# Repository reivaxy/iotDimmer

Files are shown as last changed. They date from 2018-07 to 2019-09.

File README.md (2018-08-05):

# iotDimmer

This Xiot agent is intended to control a dimmer for a lamp.

To use it, you'll preferrably also need the iotinator master module (https://github.com/reivaxy/iotinator), or you can just use it's REST API to integrate to your own designs.

You will find <a href="https://github.com/reivaxy/iotinator/wiki/07.-Dev-environnement-and-debug">here</a> all the information to install your dev environment.

I have a 15 year old big lamp that I like a lot (it was cheap !) which is equipped with a dimmer you are supposed to operate with your feet.

It's clumsy, it produces a little buzz at low level, and it's never easy to reach. Since this lamp is the main light source of my living room beside the sun, I'd like it to be a little more user friendly.

A zero crossing detection circuit sends rising edges on a pin used to trigger an interruption.

The interruption handler then computes a delay before sending a pulse to trigger a triac, to power the load (a lamp).

This way, the load is powered only between the pulse on the triac command and the next zero crossing. Changing the delay before the pulse on the triac for an incandescent bulb results in dimming the light it emits.

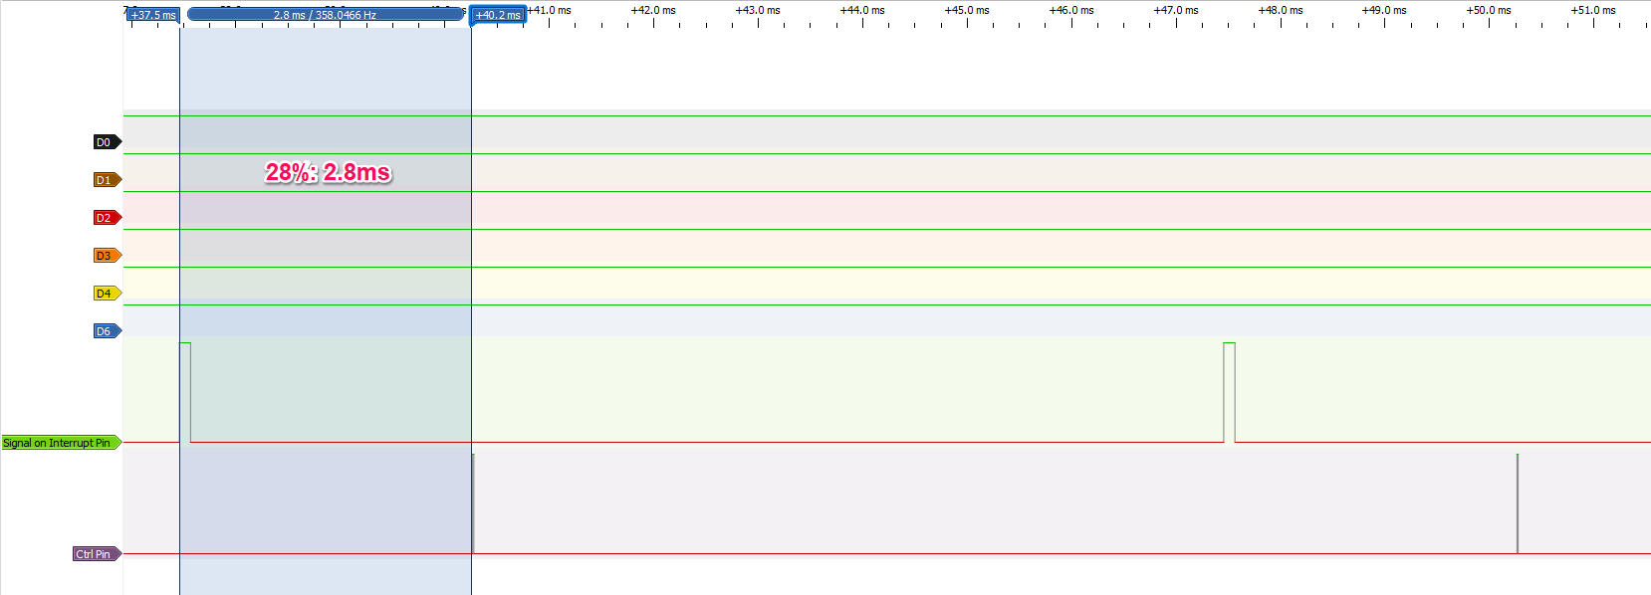
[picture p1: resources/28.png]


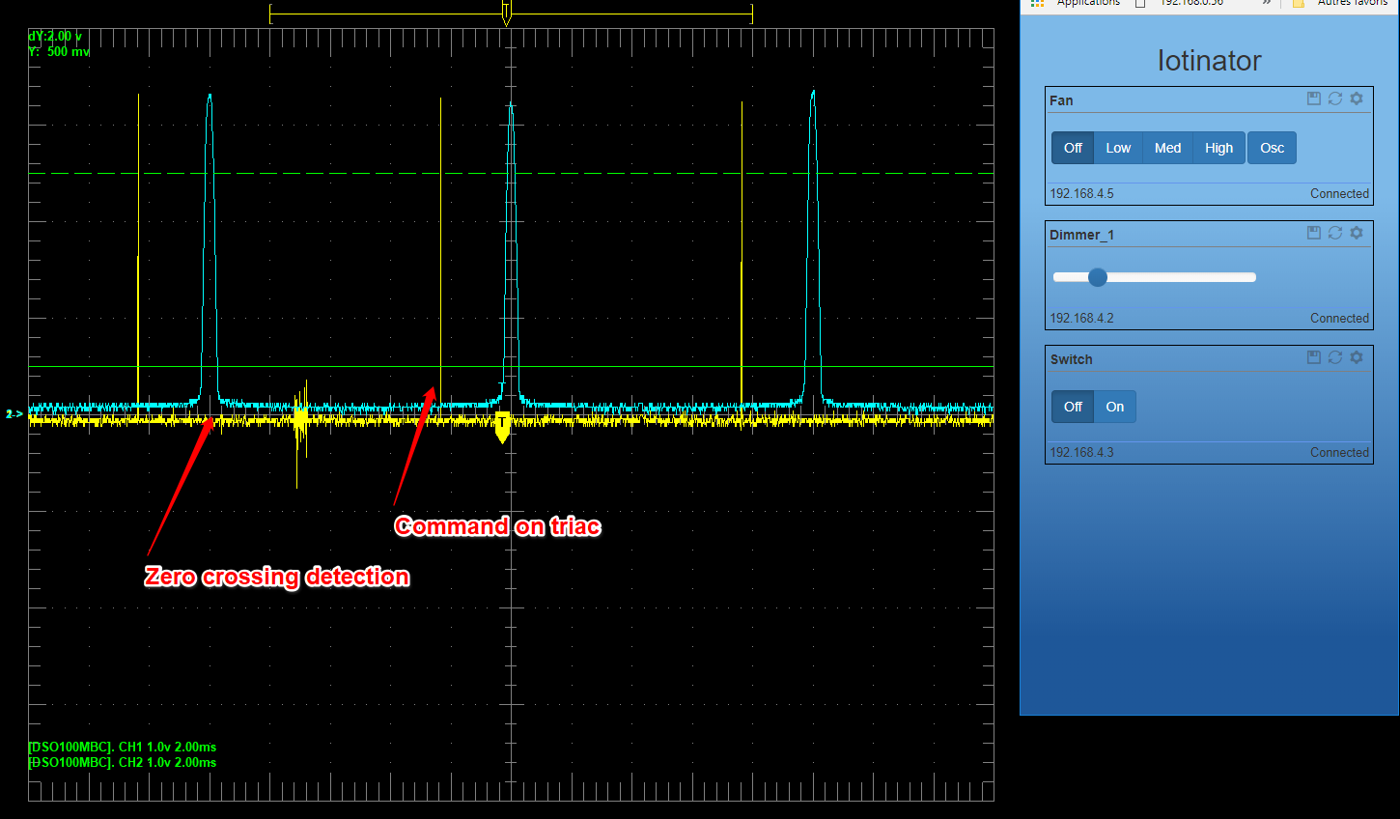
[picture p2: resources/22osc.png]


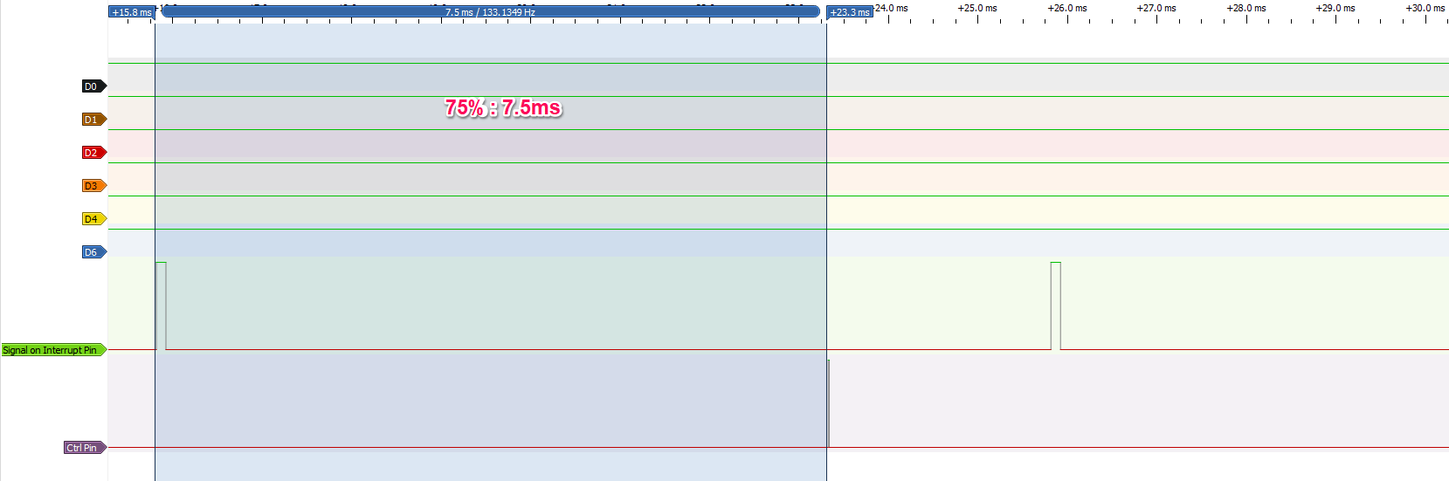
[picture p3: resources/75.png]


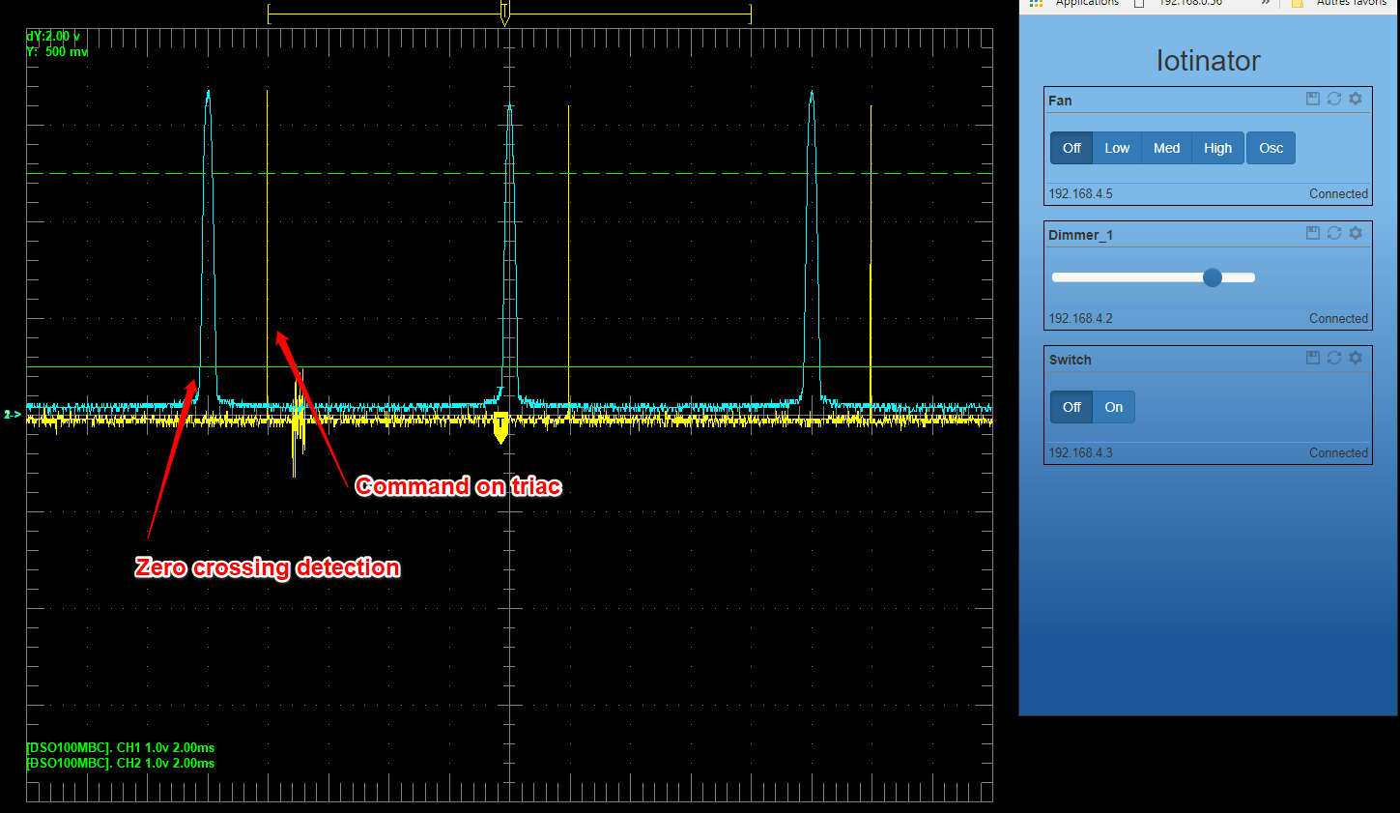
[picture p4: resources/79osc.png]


Here is the prototype for tests:

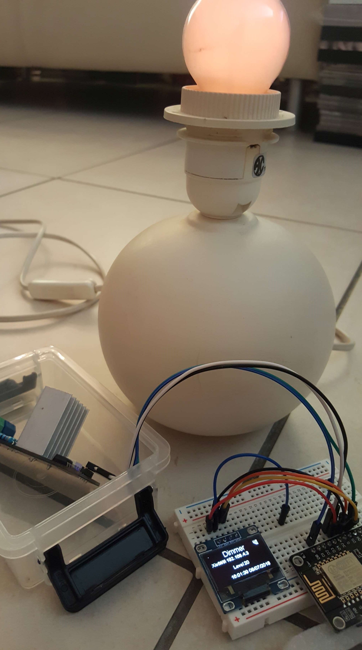
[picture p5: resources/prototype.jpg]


Here is the finished dimmer in its 3D printed case:

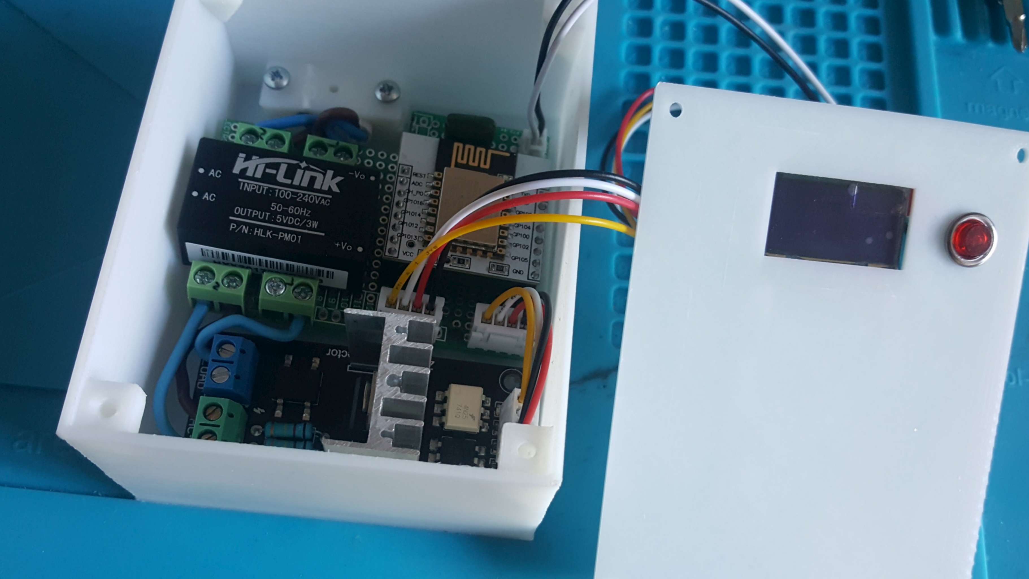
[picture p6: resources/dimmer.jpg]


And a screenshot of the webApp showing also two other modules:

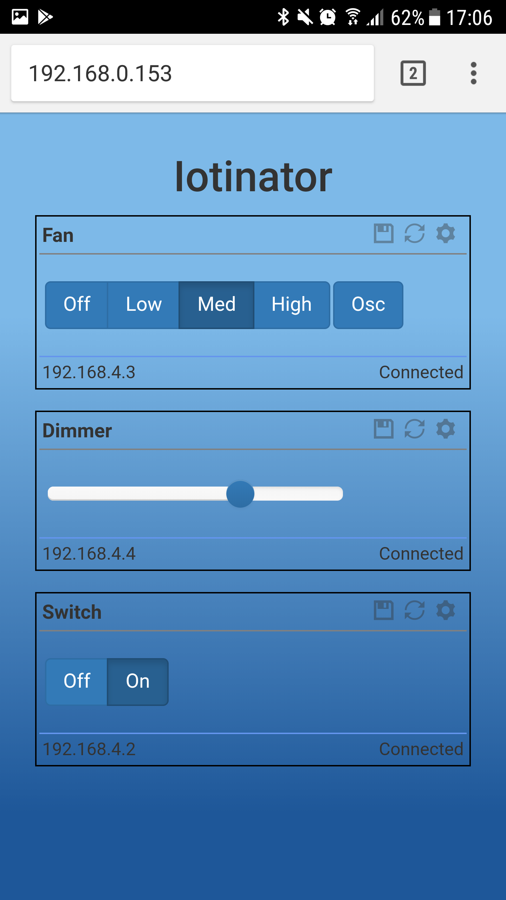
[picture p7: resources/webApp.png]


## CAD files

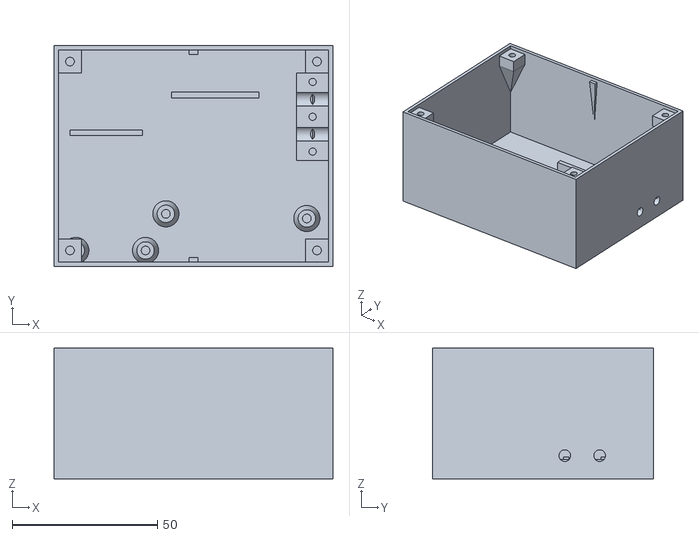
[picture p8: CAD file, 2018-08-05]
hardware/case.stl
96.0 x 76.0 x 45.0

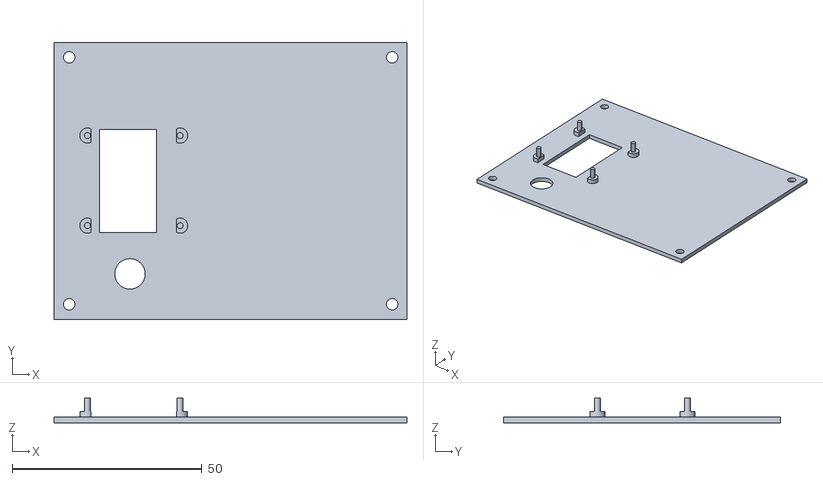
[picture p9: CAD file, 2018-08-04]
hardware/cover.stl
92.9 x 72.9 x 6.50

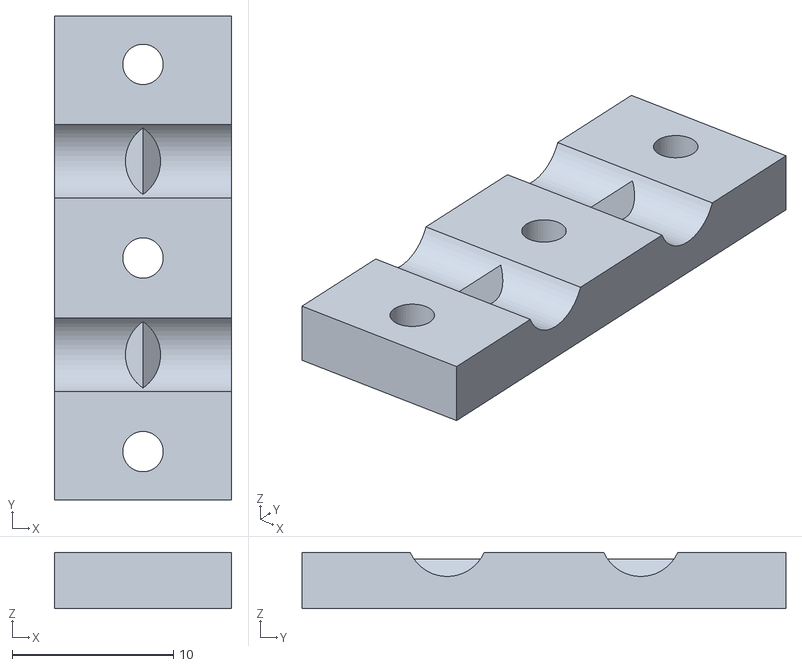
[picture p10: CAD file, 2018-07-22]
hardware/blocker.stl
11.0 x 30.0 x 3.50

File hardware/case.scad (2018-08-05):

include <../../iotinator/hardware/oledPanel.scad>;

// cover();
case();
// wireBlockerBottom();
// wireBlockerTop();
// test();
//reinforcement(wall, zi, 30);

wall = 1.5;

xi = 93;
yi = 73;
zi = 42;

x = xi + 2*wall;
y = yi + 2*wall;
z = zi + 2*wall;
bottomSpacerZ = 6;
xOffset = 6;

cornerSide = 8;
tolerance = 0.1;
oledPanelSide = 40;

module test() {
  translate([wall + tolerance/2, yi + wall + tolerance/2, z])
    rotate(180, [1, 0, 0])
      cover();
  case();
}

module cover()
{
  oledPosition = [1, (yi - tolerance - oledPanelSide) / 2, 0];
  difference()
  {
    union()
    {
      translate(oledPosition)
      rWindowPanel(oledPanelSide, oledPanelSide, wall, 0, 90);
      difference()
      {
        cube([xi - tolerance, yi - tolerance, wall]);
        translate([cornerSide / 2, cornerSide / 2, -1])
        cylinder(d = 3, h = wall + 2, $fn = 50);
        translate([cornerSide / 2, yi - cornerSide / 2, -1])
        cylinder(d = 3, h = wall + 2, $fn = 50);
        translate([xi - cornerSide / 2, cornerSide / 2, -1])
        cylinder(d = 3, h = wall + 2, $fn = 50);
        translate([xi - cornerSide / 2, yi - cornerSide / 2, -1])
        cylinder(d = 3, h = wall + 2, $fn = 50);
        // hole for the oled panel
        translate(oledPosition)
        {
          translate([0.5, 0.5, -0.5])
          cube([oledPanelSide - 1, oledPanelSide - 1, wall + 1]);
        }
      }
    }
    // Hole for the reset button
    translate([20, 12, -1])
    cylinder(d = 8, h = wall + 2, $fn = 50);
  }
}

module case() {
  difference() {
    cube([x, y, z]);  // outer shell
    translate([wall, wall, wall]) {
      cube([xi, yi, z]);
    }
    // Wire holes. TODO: params ! Should actually be part of wireBlockerBottom
    // But don't know how to make the difference for the holes...
    // or use same trick as with oled panel
    translate([xi, yi - 15.5, 8]) {
      rotate(90, [0, 1, 0]) {
        cylinder(d=4, h=5, $fn=50);
      }
    }
    translate([xi, yi - 27.5, 8]) {
      rotate(90, [0, 1, 0]) {
        cylinder(d=4, h=5, $fn=50);
      }
    }
  }
  // side reinforcement
  translate([x/2 + wall, wall, wall])
    rotate(90,[0, 0, 1])
      reinforcement(wall, zi, 20);

  // side reinforcement
  translate([x/2 - wall, y - wall, wall])
    rotate(-90,[0, 0, 1])
      reinforcement(wall, zi, 20);
  
  translate([x - 11 - wall, y - 30 - wall - 8, wall]) {
    wireBlockerBottom();
  }
  // screws for triac board
  translate([wall + xOffset, wall + 4, wall]) {
    bottomSpacer(3);
  }
  translate([wall + xOffset + 24, wall + 4, wall]) {
    bottomSpacer(3);
  }
  // Support for triac board
  translate([wall + 4, 45, wall]) {
    cube([25, 2, bottomSpacerZ]);
  }
  // Support for esp board
  translate([wall + 4 + 35, yi - 15, wall]) {
    cube([30, 2, bottomSpacerZ]);
  }

  // screws for esp board
  translate([wall + xOffset + 31, wall + 4 + 12.6, wall]) {
    bottomSpacer(3);
  }
  translate([wall + xOffset + 31 + 48.5, wall + 4 + 11, wall]) {
    bottomSpacer(3);
  }

  // corners to support the cover
  translate([wall, wall, wall])
    corner(cornerSide, zi, 20);
  translate([xi + wall, wall, wall])
    rotate(90, [0, 0, 1])
      corner(cornerSide, zi, 20);
  translate([xi + wall, yi + wall, wall])
    rotate(180, [0, 0, 1])
      corner(cornerSide, zi, 20);
  translate([wall, yi + wall, wall])
    rotate(-90, [0, 0, 1])
      corner(cornerSide, zi, 20);
}

module bottomSpacer(screwDiam) {
  translate([0, 0, 0]) {
    difference() {
      cylinder(d1 = screwDiam + 6, d2 = screwDiam + 3, h = bottomSpacerZ, $fn=50);
      translate([0, 0, 1]) {
        cylinder(d = screwDiam, h = bottomSpacerZ, $fn=50);
      }
    }
  }
}

module wireBlockerBottom(z = 6, screwThrew = false) {
  y = 30;
  x = 11;
  difference() {
    union() {
      difference() {
        cube([x, y, z]);
        // wire passage
        translate([-0.1, 9, z+1]) {
           rotate(90, [0, 1, 0]) {
             cylinder(d=5, h=x+2, $fn=50);
           }
        }
        translate([-0.1, y - 9, z+1]) {
           rotate(90, [0, 1, 0]) {
             cylinder(d=5, h=x+2, $fn=50);
           }
        }
      }
      // bottom edge to improve grip on wire
      color("lime") {
        side = z/2;
        translate([(x - sqrt(2 * side * side))/2, 0, z/2 + 0.1]) {
          rotate(45, [0, 1, 0]) {
            cube([side, y, side]);
          }
        }
      }
    }
    // Screw holes
    translate([x/2, 3, screwThrew?-0.1:0.1]) {
      cylinder(d=2.5, h=6, $fn=50);
    }
    translate([x/2, y - 3, screwThrew?-0.1:0.1]) {
      cylinder(d=2.5, h=6, $fn=50);
    }
     translate([x/2, y/2, screwThrew?-0.1:0.1]) {
       cylinder(d=2.5, h=6, $fn=50);
    }
  }
}

module wireBlockerTop() {
  wireBlockerBottom(z = 3.5, screwThrew = true);
}

module reinforcement(side, height, zOffset) {
  angle = 20;
  translate([0, side, 0])
    difference() {
      translate([0, 0, zOffset])
        linear_extrude(height = height - zOffset, center = false, convexity = 10, scale=side*200)
          square(size = .01, center = true);
      translate([-side, -side, 0])
        cube([side, side*2, height +1]);
    }
} 

module corner(side, height, zOffset, holeDiam = 3) {
  angle = 20;
  difference() {
    color("aqua") {
     translate([0, 0, height - 5]) {
       difference() {
         cube([side, side, 5]);
         translate([side/2, side/2, 0.1]) {
           cylinder(d=holeDiam, h=6, $fn=50);
         }
       }
     }
     translate([0, 0, zOffset])
      linear_extrude(height = height - zOffset - 5, center = false, convexity = 10, scale=side*200)
         square(size = .01, center = true);
    }
    translate([-side, -side, 0])
      cube([side, side, height]);
    translate([-side, 0, 0])
      cube([side, side, height]);
    translate([0, -side, 0])
      cube([side, side, height]);
  }
}

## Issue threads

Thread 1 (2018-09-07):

Add an arduino nano to handle the ZX and triac

reivaxy, 2018-09-07:
The first version of the dimmer used to start handling the zero-crossed exception as soon as the module was powered.
Now, to ensure a faster connection to the master wifi network, the interruption handler is set only once the agent is connected.
As a result, there is a delay before the dimmed device turns on.

A nano arduino could handle the ZC interruption and drive the triac. The ESP would just provide it (through serial) with the delay value when it's changed.

Problem: OTA! The code for the Nano would have to be flashed by the ESP through the serial port... This is a lot of work.

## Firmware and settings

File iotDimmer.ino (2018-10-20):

/**
 *  iotinator Dimmer Agent module
 *  Xavier Grosjean 2018
 *  Creative Commons Attribution-NonCommercial-ShareAlike 4.0 International Public License
 */
 

#if F_CPU != 160000000
  CPU FREQUENCY MUST BE SET TO 160MHz !!
#endif

#include <stdio.h>
#include "DimmerModule.h"

#include "config.h"

#define API_VERSION "1.0"    // modules can check API version to make sure they are compatible...

// Global object to store config
DimmerConfigClass *config;
XIOTModule* module;

int scl = 12;
int sda = 14;

void setup(){
  int intPin = 13;
  int ctrlPin = 5;
  
  // After a reset, interrupt handlers may still be operating ??
  detachInterrupt(digitalPinToInterrupt(intPin));

  Serial.begin(9600);
  delay(500); // time to connect serial
  
  config = new DimmerConfigClass((unsigned int)CONFIG_VERSION, (char*)MODULE_NAME);
  config->init();
 
  module = new DimmerModule(config, 0x3C, sda, scl, intPin, ctrlPin);
}

/*********************************
 * Main Loop
 *********************************/
void loop() {
  // Mandatory periodic call, to refresh display, Clock, check requests
  // on the http API, ...
  module->loop();
}

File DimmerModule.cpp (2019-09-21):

/**
 *  iotinator Dimmer Agent module
 *  Xavier Grosjean 2018
 *  Creative Commons Attribution-NonCommercial-ShareAlike 4.0 International Public License
 */

#include "DimmerModule.h"
#include <FunctionalInterrupt.h>


DimmerModule::DimmerModule(DimmerConfigClass* config, int displayAddr, int displaySda, int displayScl, int intPin, int ctrlPinParam):XIOTModule(config, displayAddr, displaySda, displayScl) {
  pinMode(intPin, INPUT_PULLUP);
  _intPin = intPin;
  pinMode(ctrlPinParam, OUTPUT);
  _ctrlPin = ctrlPinParam;
  _oledDisplay->setLineAlignment(2, TEXT_ALIGN_CENTER);
  setLevel(config->getDefaultLevel());
  
}

void DimmerModule::customOnStaGotIpHandler(WiFiEventStationModeGotIP ipInfo) {
  Serial.println("Init interrupt handler");
  attachInterrupt(digitalPinToInterrupt(_intPin), std::bind(&DimmerModule::intHandler, this), RISING);

}

// Handler for the interruption received when crossing 0
// Code found on Amazon description of triac + zero crossing detection module
void DimmerModule::intHandler() {
  // Firing angle calculation : 1 full 50Hz wave =1/50=20ms
  // Every zerocrossing : (50Hz)-> 10ms (1/2 Cycle) For 60Hz (1/2 Cycle) => 8.33ms
  // 10ms=10000us
  if(_lightLevelDelay > 9600) {
    digitalWrite(_ctrlPin, LOW);    // triac Off
    return;
  }
  delayMicroseconds(_lightLevelDelay);    // Off cycle
  digitalWrite(_ctrlPin, HIGH);   // triac firing
  delayMicroseconds(10);         // triac On propogation delay (for 60Hz use 8.33)
  digitalWrite(_ctrlPin, LOW);    // triac Off
}

bool DimmerModule::customBeforeOTA() {
  Serial.println("Detaching interrupts for OTA");
  detachInterrupt(digitalPinToInterrupt(_intPin));
  return true;
}


char* DimmerModule::_customData() {
//  Serial.println("DimmerModule::_customData");
  char* data = (char *)malloc(100);
  sprintf(data, "{\"level\":%d}", _level);
  return data;
}

char* DimmerModule::useData(char* data, int* httpCode) {
Serial.println("dimmer");
Serial.println(data);
  const int bufferSize = 2*JSON_OBJECT_SIZE(1);
  StaticJsonBuffer<bufferSize> jsonBuffer;
  JsonObject& root = jsonBuffer.parseObject(data);
  if (!root.success()) {
    _oledDisplay->setLine(1, "Got bad data", TRANSIENT, NOT_BLINKING);
  } else {
    int level = (int)root["level"];
    Serial.printf("New level: %d\n", level);
    setLevel(level);
  }
  *httpCode = 200;
  return emptyMallocedResponse();
}

void DimmerModule::setLevel(int levelParam) {
  _level = levelParam;
  _lightLevelDelay = (100 - _level) * 100;   // Delay in ms before triggering triac
  Serial.printf("LevelDelay %d\n", _lightLevelDelay);

  refreshDisplay();
}

void DimmerModule::refreshDisplay() {
  char message[100];
  sprintf(message, "Level  %d", _level);
  _oledDisplay->setLine(2, message, NOT_TRANSIENT, NOT_BLINKING);
  sprintf(message, "FCPU  %d", F_CPU);
  _oledDisplay->setLine(3, message, NOT_TRANSIENT, NOT_BLINKING);
}

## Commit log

2018-07-14 Replaced "slave" with "agent" to avoid problems when Skynet rules the world.
    [DimmerModule.cpp, iotDimmer.ino]
2018-07-14 Begining of dimmer case
    [case.scad]
2018-07-15 added corner cut pillars, wire blocker
    [case.scad]
2018-07-15 Added wire holes, esp board support
    [case.scad]
2018-07-15 Adjustments Larger cable blocker
    [case.scad]
2018-07-21 Interruption initialization asap, not waiting for registration, in order to turn light on immediately
2018-08-04 Added cover, stronger screw pillars
    [case.scad]
2018-08-04 Cover with Oled and reset button holes
    [case.scad, case.stl, cover.stl]
2018-08-05 Added cover supports on the long sides
    [case.scad, case.stl]
2018-08-29 Added todo check std::bind for interruption handler
2018-08-30 Using std::bind to attach interrupt handler No longer attaching it before connecting to master: failing too oftent. Need to refactor the handler to no longer block waiting
    [DimmerModule.cpp]
2018-10-20 Finally found out why it would no longer connect to wifi if interruption was already set up, after it initially worked: Needs to run at 160MHz ! => have included code that breaks compilation if speed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
    [DimmerModule.cpp, iotDimmer.ino]
2018-10-20 My bad, CPU freq is not the culprit. OTA is. Just initiating an OTA, and aborting will totally break the program: reset when trying to connect to wifi
    This reverts commit b0b4c1f031eb81fac25e737e013e570b18df1b86.
    [DimmerModule.cpp, iotDimmer.ino]
